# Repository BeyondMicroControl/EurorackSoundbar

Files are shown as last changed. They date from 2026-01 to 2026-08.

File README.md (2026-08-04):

# Eurorack Soundbar
Goal: A table with fitting speaker & synth electronics for a MIDI keyboard.

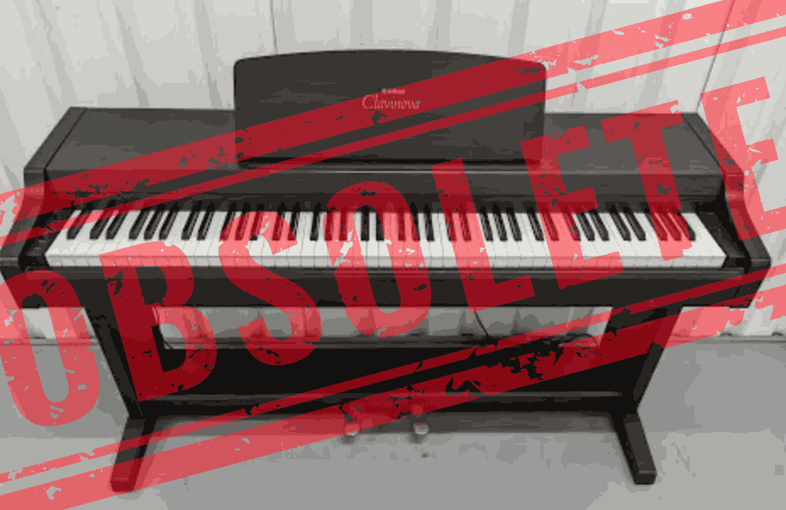
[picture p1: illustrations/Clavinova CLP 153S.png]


# Piano enclosures deserve better design
It all started with buying an all-in-one furnished hammer-action piano with built-in synth and speakers, but ending 25 years later with a shell containing a terribly old synth and procrastinating MIDI interface.  That said, while build quality on all parts of the piano gracefull survived decades of playing, electronics inside turned out to be fashion-sensitive. As a matter of fact, furniture built-in synths sooner or later all become **OBSOLETE**. I long thought about flinging out the guts out of my good old Clavinova from Yamaha built around a synth chip from 1991 (YMW258-F), but selling my old piano in its original state and figure out a more future-proof enclosure sounded like a better idea, as I really wanted an enclosure allowing more flexibility.  So, here's the plan: 
* Buy a multi-sensor MIDI keyboard - I fell for a KAWAI VPC1, but any model will do.
* Design a slim, good-looking table on wheels carrying about 30Kg=66lbs of keyboard and another 20Kg=44lbs of soundbar.
* Design a soundbar including a standardised built-in rack space for replacable electronics : **A Eurorack Soundbar as it were!**

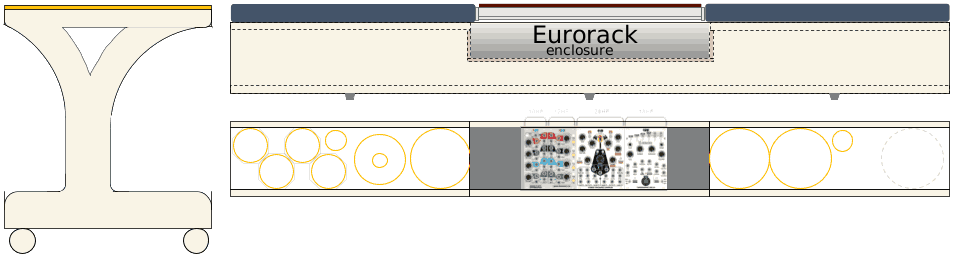
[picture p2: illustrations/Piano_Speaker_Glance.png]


# Eurorack Soundbar Requirements
## Furniture
1.1) Elegant & aesthetically matching the MIDI keyboard<br>
1.2) Providing table surface fitting Piano Keyboard + Soundbar.<br>
1.3) Sturdy enough to bear stress and strain caused by ~50Kg=110lbs of weight<br>
1.4) Providing maximum leg space horizontally and vertically.<br>
1.5) Height-adjustable to some extent.<br>
1.6) Piano-black glossy paint finish.<br>

## Speaker enclosure - passive part
2.1) Perfectly fitting keyboard width, and height aligned with the top of the speaker grills.<br>
2.2) Best compromise between good bass production and small enclosure volume.<br>
2.3) Rich sound spectrum and spatial perception ideal for instrument sound reproduction.<br>
2.4) Optional built-in passive filter and accessble attenuators whenever necessary.<br>
2.5) Die-cast, anti-reflection and airleak-proof speaker enclosure.<br>
2.6) Vibration isolation between table & enclosure.<br>
2.7) Does not vibrate or glide off the table.<br>
2.8) Re-openable, allowing replacement of speakers provided with inside fixture.<br>
2.9) All speaker leads and filter leads come straight out of the pressure cabinet. (No electrical circuits inside)<br>
2.10) One common connector (male part) providing electrically separate access to all enclosed speakers and filters.<br>
2.11) Nicely fitting speaker cover frame wrapped in speaker cover fabric, with magnetic attachment<br>
2.12) Speakers pointing upwards, providing a fairly unobstructed sound path<br>

## Electronics enclosure - active part
3.1) One common connector (female part, heading towards the amplifier) with configurable dispatching jumpers.<br>
3.2) Standard Eurorack frame housing 3U 84HP (decisive for speaker enclosure depth).<br>
3.3) Eurorack power source (Low noise 15-35V source for Amps, 5V & 3V3 regulated source for MCU's and controllers), optionally with a 1-button on/off and power-on sequence.<br>
3.4) A good compromise on the divide between Eurorack enclosure height (located between bottom plate and face plate) and speaker enclosure duct height (located under the Eurorack bottom plate).<br>
3.6) Mains inlet connector with fast fuse and manual switch.<br>
3.5) At least 3 essential Eurorack modules<br>
   - Amp (2 x 30-80W)
   - Piano connector face plate (USB-midi, MIDI-in/out)
   - Synth module (MIDI-in to audio)

3.6) Optional Eurorack modules - just brainstorming<br>
   - Battery module providing mobile power
   - Additional experimental synths (without patch cable clutter)
   - MIDI merger/splitter module
   - MIDI controller module (encoders, buttons, sliders, tone wheels, LEDs, touchscreens...)
   - MIDI sequencer / tempo

# Getting sketchy with it
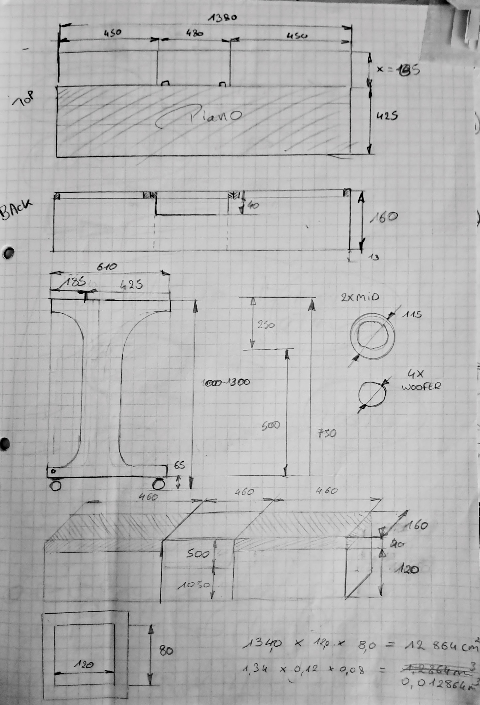
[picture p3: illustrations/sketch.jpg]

This is the initial sketch, for what it's worth, outlining all elements including the Piano; we'll come back later on the exact measures and additional features; obviously depending on the MIDI keyboard outer dimensions one has purchased.  

This is our first step, planning how this soundbar will fit best fit behind your MIDI keyboard, the outer dimensions of the table, how your knees will ideally fit under that table, and many other practical considerations.

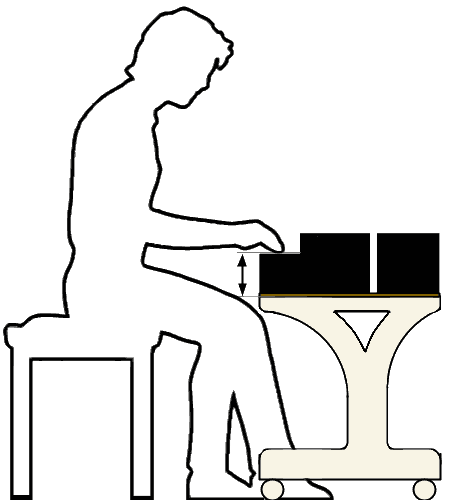
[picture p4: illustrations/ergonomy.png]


# Hardware

<a href="https://beyondmicrocontrol.github.io/AsciiCAD/index.html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">Input module</a>

# Tools

<a href=https://beyondmicrocontrol.github.io/EurorackSoundbar/tools/TOOLS_CATALOG.html>TOOLS</a>

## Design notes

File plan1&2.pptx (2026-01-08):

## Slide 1

Scrap full-range
80W 6ohm

255mm

460mm

129.5mm

255mm

PASSIVE
RADIATOR

460mm

Scrap surround system
Bass drivers 8ohm

Ebay 25W dome
Tweeter 8ohm

BASS

4

BASS

2

65mm

BASS

1

BASS

3

172mm

56mm

Volvo C70 scrap midrange dome 8ohm

56mm

172mm

7

TR

40mm

110mm

TREBLE

BASS

5

116mm

Rail from sliding door

MID

6

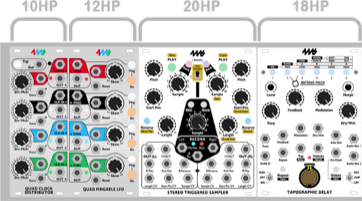
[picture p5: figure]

460mm / 5.08 = 90 HP

116mm

MID

Epoxy rain gutter plate

8

9

10

TR

40mm

OPTIONAL
BASS

146mm

7

/57

6mm

22.2mm

26mm

7.4mm

72 mm

98mm

114mm

/18

146mm

122mm

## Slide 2

1380mm

460mm

702mm

Std. Eurorack frame

speaker
textile

175mm

460mm

460mm

26mm

6mm

98mm

connector hole

137mm

140mm

160mm

/57

25mm

12mm

575mm

Rail from sliding door

375mm

12mm

50mm

Epoxy rain gutter front plate

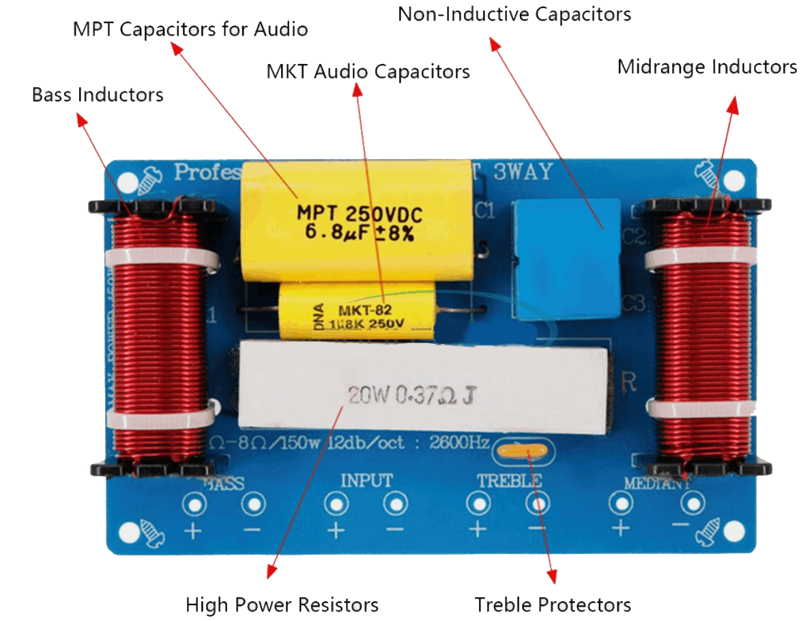
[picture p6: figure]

283mm

375mm

165mm

283mm

Passive filter
Circuit design

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
filter

8Ω

6Ω

2.2Ω

8Ω

8Ω

10

filter

2.2Ω

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
630mm

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
Connector HAT

167mm

125mm

283mm

Crossover filter

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
jumpers

102mm

F

J

J

J

J

J

J

AMP-

F

/78.7

61mm

H

M

L

L

M

H

AMP+

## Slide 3

DRAFT!!!

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
AMP-

AMP-

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
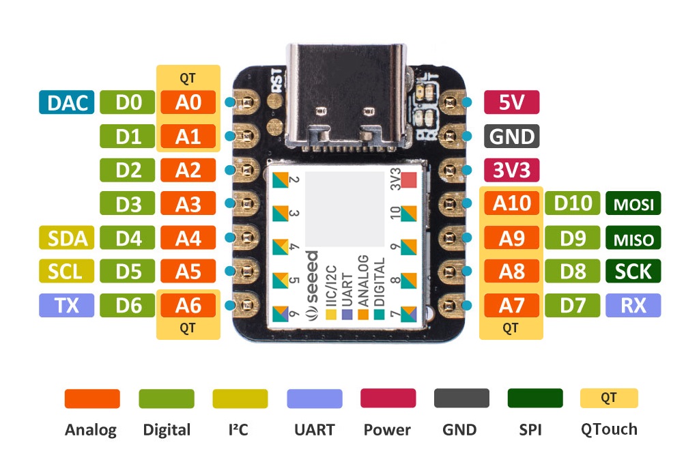
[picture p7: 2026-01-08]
illustrations/Seeeduino-XIAO-pinout-1.jpg

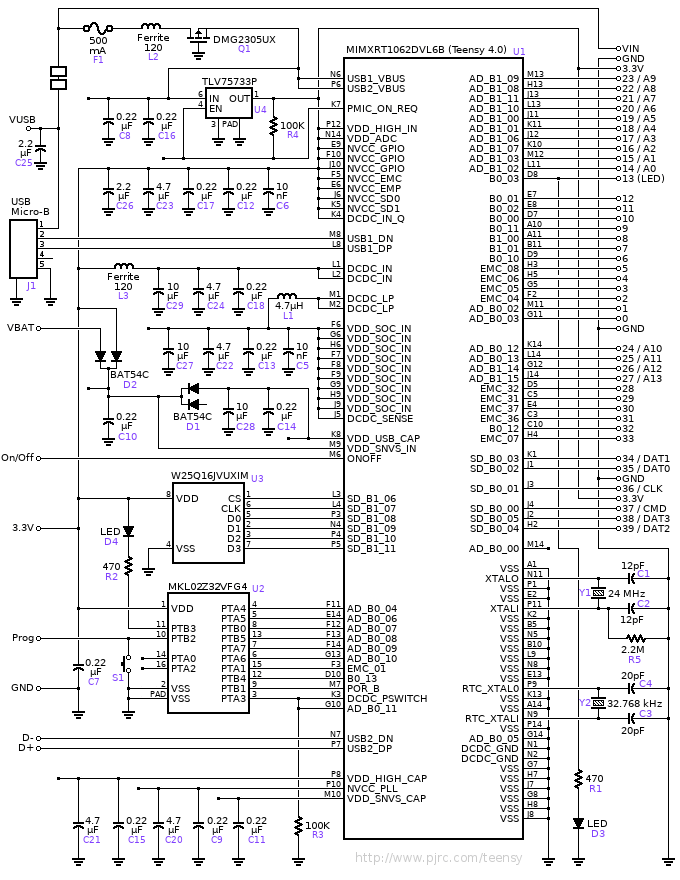
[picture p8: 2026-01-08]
arduino/Teensy40/Teensy-4.0-schematic.png

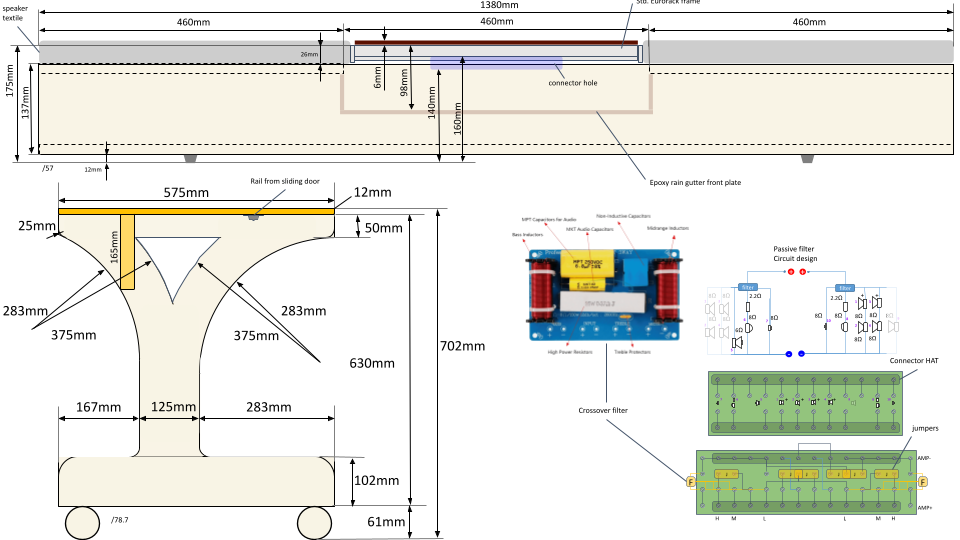
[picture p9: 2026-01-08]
plan2.png

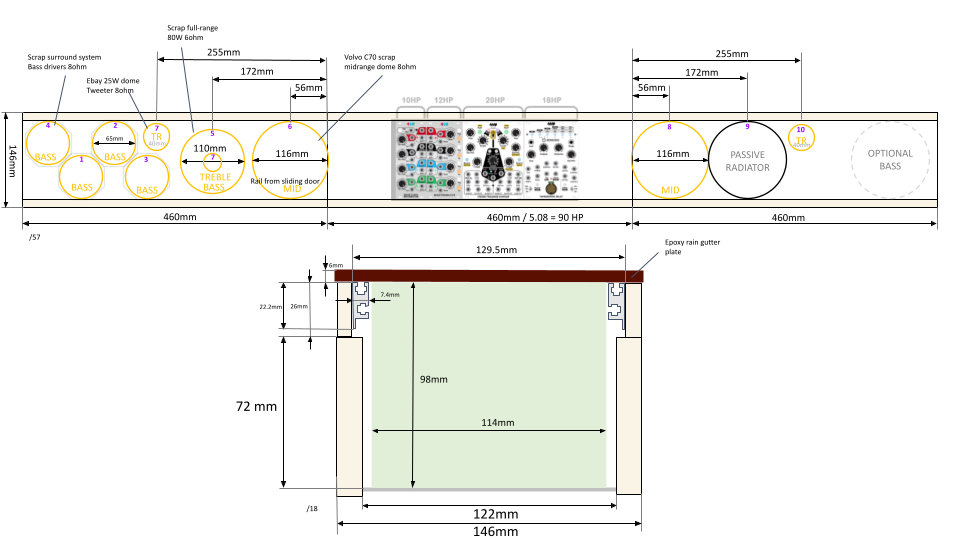
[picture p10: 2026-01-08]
plan1.png

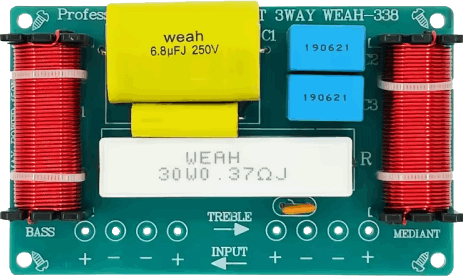
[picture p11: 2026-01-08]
illustrations/crossover-4.png

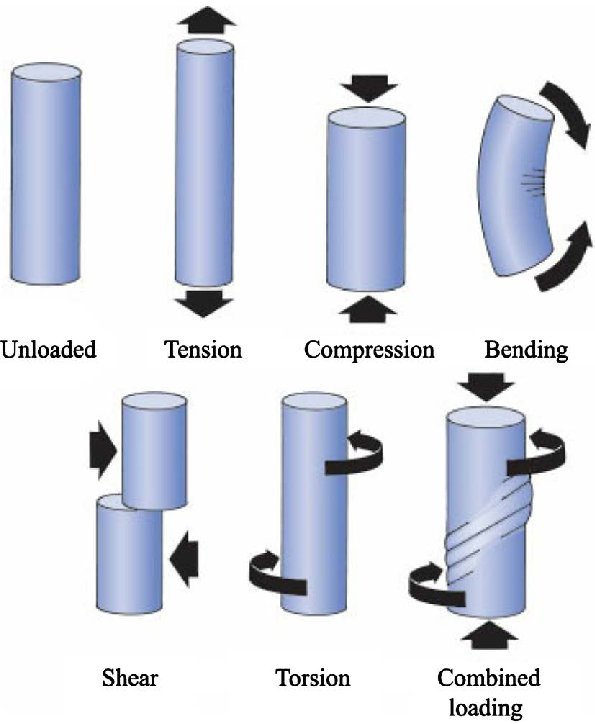
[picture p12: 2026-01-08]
illustrations/loading-cases.jpg

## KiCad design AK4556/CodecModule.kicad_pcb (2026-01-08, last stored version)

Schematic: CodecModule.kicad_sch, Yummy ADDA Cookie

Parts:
C1, C3, C4, C5: 10u; CP_Elec_4x5.4
C2, C6, C9: 100n; C_0603_1608Metric_Pad1.05x0.95mm_HandSolder
C7, C8: 22u; CP_Elec_4x5.4
C10: 2u2; CP_Elec_4x5.4
J1, J2: Conn_01x09_Female; HalfHole_2x9
R3: 5R1; R_0603_1608Metric_Pad1.05x0.95mm_HandSolder
R4, R5, R6, R7, R8: 51R; R_0603_1608Metric_Pad1.05x0.95mm_HandSolder
R9, R10, R11: 10k; R_0603_1608Metric_Pad1.05x0.95mm_HandSolder
R12, R13: 220R; R_0603_1608Metric_Pad1.05x0.95mm_HandSolder
U1: AK4556; TSSOP-20_4.4x6.5mm_P0.65mm

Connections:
+3.3VA: C5.1, C6.1, J1.4, R3.2, U1.4, U1.6
/AUDIO_INL: C4.1, J1.1
/AUDIO_INR: C3.1, J1.2
/AUDIO_OUTL: J2.9, R13.1
/AUDIO_OUTR: J2.8, R12.1
/CKS0: J1.5, U1.9
/CKS1: J1.6, U1.10
/CKS2: J1.7, U1.11
/CKS3: J1.8, U1.12
/I2S_BCLK: J2.6, R5.1
/I2S_DIN: J2.2, R8.1
/I2S_DOUT: J2.1, R4.2
/I2S_LRCLK: J2.4, R7.1
/I2S_MCLK: J2.5, R6.1
/PDN: J1.9, R11.2, U1.17
/VD: C1.1, C2.1, R3.1, U1.5
GNDA: C1.2, C2.2, C5.2, C6.2, C9.2, C10.2, J1.3, J2.3, J2.7, R9.1, R10.1, R11.1, U1.3, U1.7
unnamed: C3.2, U1.1
unnamed: C4.2, U1.2
unnamed: C7.1, U1.20
unnamed: C7.2, R9.2, R12.2
unnamed: C8.1, U1.19
unnamed: C8.2, R10.2, R13.2
unnamed: C9.1, C10.1, U1.18
unnamed: R4.1, U1.8
unnamed: R5.2, U1.16
unnamed: R6.2, U1.15
unnamed: R7.2, U1.14
unnamed: R8.2, U1.13

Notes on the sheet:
place near VD/VSS pin
De-emphasis filter off

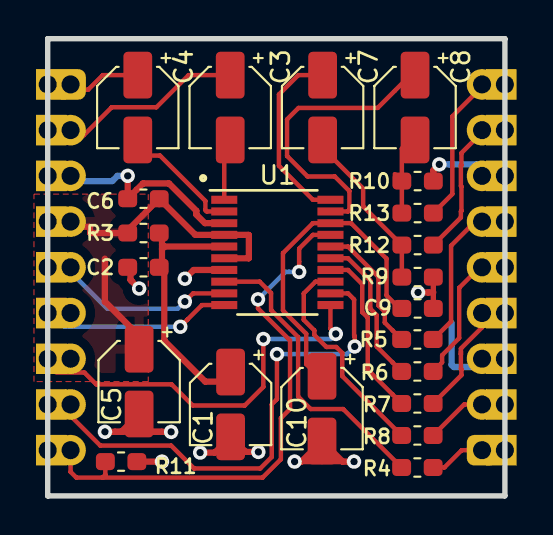
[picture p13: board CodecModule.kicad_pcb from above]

Board: 2 copper layers, 25.4 x 25.4 mm, 24 parts (0 on the bottom side), 29 nets.

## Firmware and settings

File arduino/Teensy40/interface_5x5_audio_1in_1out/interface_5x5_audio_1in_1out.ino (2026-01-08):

/* Create a "class compliant " USB to 3 MIDI IN and 3 MIDI OUT interface.

   MIDI receive (6N138 optocoupler) input circuit and series resistor
   outputs need to be connected to Serial1, Serial2 and Serial3.

   You must select MIDIx4 from the "Tools > USB Type" menu

   This example code is in the public domain.
*/

#include <MIDI.h>

// Create the Serial MIDI ports
MIDI_CREATE_INSTANCE(HardwareSerial, Serial1, MIDI1);
MIDI_CREATE_INSTANCE(HardwareSerial, Serial2, MIDI2);
MIDI_CREATE_INSTANCE(HardwareSerial, Serial3, MIDI3);
MIDI_CREATE_INSTANCE(HardwareSerial, Serial4, MIDI4);
MIDI_CREATE_INSTANCE(HardwareSerial, Serial5, MIDI5);
MIDI_CREATE_INSTANCE(HardwareSerial, Serial6, MIDI6);

// A variable to know how long the LED has been turned on
elapsedMillis ledOnMillis;
const float noteFreqs[128] = {8.176, 8.662, 9.177, 9.723, 10.301, 10.913, 11.562, 12.25, 12.978, 13.75, 14.568, 15.434, 16.352, 17.324, 18.354, 19.445, 20.602, 21.827, 23.125, 24.5, 25.957, 27.5, 29.135, 30.868, 32.703, 34.648, 36.708, 38.891, 41.203, 43.654, 46.249, 48.999, 51.913, 55, 58.27, 61.735, 65.406, 69.296, 73.416, 77.782, 82.407, 87.307, 92.499, 97.999, 103.826, 110, 116.541, 123.471, 130.813, 138.591, 146.832, 155.563, 164.814, 174.614, 184.997, 195.998, 207.652, 220, 233.082, 246.942, 261.626, 277.183, 293.665, 311.127, 329.628, 349.228, 369.994, 391.995, 415.305, 440, 466.164, 493.883, 523.251, 554.365, 587.33, 622.254, 659.255, 698.456, 739.989, 783.991, 830.609, 880, 932.328, 987.767, 1046.502, 1108.731, 1174.659, 1244.508, 1318.51, 1396.913, 1479.978, 1567.982, 1661.219, 1760, 1864.655, 1975.533, 2093.005, 2217.461, 2349.318, 2489.016, 2637.02, 2793.826, 2959.955, 3135.963, 3322.438, 3520, 3729.31, 3951.066, 4186.009, 4434.922, 4698.636, 4978.032, 5274.041, 5587.652, 5919.911, 6271.927, 6644.875, 7040, 7458.62, 7902.133, 8372.018, 8869.844, 9397.273, 9956.063, 10548.08, 11175.3, 11839.82, 12543.85};
const float DIV127 = (1.0 / 127.0);

#include <Audio.h>

// GUItool: begin automatically generated code
AudioSynthWaveformSine   sine1;          //xy=180,469
//AudioSynthWaveformSineHires   sine1;
AudioOutputMQS        mqs1;           //xy=380,468
AudioConnection          patchCord1(sine1, mqs1);
// GUItool: end automatically generated code

void setup() {
  Serial.begin(31250);
 
  pinMode(13, OUTPUT); // LED pin
  MIDI1.begin(MIDI_CHANNEL_OMNI);
  MIDI2.begin(MIDI_CHANNEL_OMNI);
  MIDI3.begin(MIDI_CHANNEL_OMNI);
  MIDI4.begin(MIDI_CHANNEL_OMNI);
  MIDI5.begin(MIDI_CHANNEL_OMNI);
  MIDI6.begin(MIDI_CHANNEL_OMNI);
  MIDI1.turnThruOff();
  MIDI2.turnThruOff();
  MIDI3.turnThruOff();
  MIDI4.turnThruOff();
  MIDI5.turnThruOff();
  MIDI6.turnThruOff();


  AudioMemory(12);
  sine1.amplitude(0.0);
  sine1.frequency(1000);
 
    digitalWriteFast(13, HIGH); // LED on
    delay(1500);
    digitalWriteFast(13, LOW);
}


void loop() {
  bool activity = false;

  if (MIDI1.read()) {
    // get a MIDI IN1 (Serial) message
    byte type = MIDI1.getType();
    byte channel = MIDI1.getChannel();
    byte data1 = MIDI1.getData1();
    byte data2 = MIDI1.getData2();

    // forward the message to USB MIDI virtual cable #0
    if (type != midi::SystemExclusive) {
      // Normal messages, simply give the data to the usbMIDI.send()
      usbMIDI.send(type, data1, data2, channel, 0);
      MIDI1.send(static_cast<midi::MidiType>(type), data1, data2, channel);
      MIDI6.send(static_cast<midi::MidiType>(type), data1, data2, channel);
 
   /* 
      MIDI2.send(type, data1, data2, channel);
      MIDI3.send(type, data1, data2, channel);      
      MIDI4.send(type, data1, data2, channel);  
      MIDI5.send(type, data1, data2, channel);  
   */

      char c[256];
      sprintf(c,"%d %d %d",data1,data2,channel);
      Serial.println(c);
   
    } else {
      // SysEx messages are special.  The message length is given in data1 & data2
      unsigned int SysExLength = data1 + data2 * 256;
      usbMIDI.sendSysEx(SysExLength, MIDI1.getSysExArray(), true, 0);
 /*   MIDI1.sendSysEx(SysExLength, MIDI1.getSysExArray(), true);
      MIDI2.sendSysEx(SysExLength, MIDI1.getSysExArray(), true);
      MIDI3.sendSysEx(SysExLength, MIDI1.getSysExArray(), true);
      MIDI4.sendSysEx(SysExLength, MIDI1.getSysExArray(), true);
      MIDI5.sendSysEx(SysExLength, MIDI1.getSysExArray(), true);
   */
   
    }
    activity = true;
  }

  if (MIDI2.read()) {
    // get a MIDI IN2 (Serial) message
    byte type = MIDI2.getType();
    byte channel = MIDI2.getChannel();
    byte data1 = MIDI2.getData1();
    byte data2 = MIDI2.getData2();

    // forward the message to USB MIDI virtual cable #1
    if (type != midi::SystemExclusive) {
      // Normal messages, simply give the data to the usbMIDI.send()
      usbMIDI.send(type, data1, data2, channel, 1);
/*      MIDI1.send(type, data1, data2, channel);
      MIDI2.send(type, data1, data2, channel);
      MIDI3.send(type, data1, data2, channel);  
      MIDI4.send(type, data1, data2, channel);  
      MIDI5.send(type, data1, data2, channel);  
  */    
    } else {
      // SysEx messages are special.  The message length is given in data1 & data2
      unsigned int SysExLength = data1 + data2 * 256;
      usbMIDI.sendSysEx(SysExLength, MIDI2.getSysExArray(), true, 1);
  /*    MIDI1.sendSysEx(SysExLength, MIDI2.getSysExArray(), true);
      MIDI2.sendSysEx(SysExLength, MIDI2.getSysExArray(), true);
      MIDI3.sendSysEx(SysExLength, MIDI2.getSysExArray(), true);
      MIDI4.sendSysEx(SysExLength, MIDI2.getSysExArray(), true);
      MIDI5.sendSysEx(SysExLength, MIDI2.getSysExArray(), true);      
  */  
    }
    activity = true;
  }

  if (MIDI3.read()) {
    // get a MIDI IN1 (Serial) message
    byte type = MIDI3.getType();
    byte channel = MIDI3.getChannel();
    byte data1 = MIDI3.getData1();
    byte data2 = MIDI3.getData2();

    // forward the message to USB MIDI virtual cable #0
    if (type != midi::SystemExclusive) {
      // Normal messages, simply give the data to the usbMIDI.send()
      usbMIDI.send(type, data1, data2, channel, 2);
  /*    MIDI1.send(type, data1, data2, channel);
      MIDI2.send(type, data1, data2, channel);
      MIDI3.send(type, data1, data2, channel);
      MIDI4.send(type, data1, data2, channel);  
      MIDI5.send(type, data1, data2, channel);          
   */  
    } else {
      // SysEx messages are special.  The message length is given in data1 & data2
      unsigned int SysExLength = data1 + data2 * 256;
      usbMIDI.sendSysEx(SysExLength, MIDI3.getSysExArray(), true, 2);
 /*     MIDI1.sendSysEx(SysExLength, MIDI3.getSysExArray(), true);
      MIDI2.sendSysEx(SysExLength, MIDI3.getSysExArray(), true);
      MIDI3.sendSysEx(SysExLength, MIDI3.getSysExArray(), true);
      MIDI4.sendSysEx(SysExLength, MIDI3.getSysExArray(), true);
      MIDI5.sendSysEx(SysExLength, MIDI3.getSysExArray(), true);      
 */  
    }
    activity = true;
  }

  if (MIDI4.read()) {
    // get a MIDI IN1 (Serial) message
    byte type = MIDI4.getType();
    byte channel = MIDI4.getChannel();
    byte data1 = MIDI4.getData1();
    byte data2 = MIDI4.getData2();

    // forward the message to USB MIDI virtual cable #0
    if (type != midi::SystemExclusive) {
      // Normal messages, simply give the data to the usbMIDI.send()
      usbMIDI.send(type, data1, data2, channel, 3);
 /*     MIDI1.send(type, data1, data2, channel);
      MIDI2.send(type, data1, data2, channel);
      MIDI3.send(type, data1, data2, channel);
      MIDI4.send(type, data1, data2, channel);  
      MIDI5.send(type, data1, data2, channel);          
  */    
    } else {
      // SysEx messages are special.  The message length is given in data1 & data2
      unsigned int SysExLength = data1 + data2 * 256;
      usbMIDI.sendSysEx(SysExLength, MIDI4.getSysExArray(), true, 3);
  /*    MIDI1.sendSysEx(SysExLength, MIDI4.getSysExArray(), true);
      MIDI2.sendSysEx(SysExLength, MIDI4.getSysExArray(), true);
      MIDI3.sendSysEx(SysExLength, MIDI4.getSysExArray(), true);
      MIDI4.sendSysEx(SysExLength, MIDI4.getSysExArray(), true);
      MIDI5.sendSysEx(SysExLength, MIDI4.getSysExArray(), true);      
   */
    }
    activity = true;
  }

  if (MIDI5.read()) {
    // get a MIDI IN1 (Serial) message
    byte type = MIDI5.getType();
    byte channel = MIDI5.getChannel();
    byte data1 = MIDI5.getData1();
    byte data2 = MIDI5.getData2();

    // forward the message to USB MIDI virtual cable #0
    if (type != midi::SystemExclusive) {
      // Normal messages, simply give the data to the usbMIDI.send()
      usbMIDI.send(type, data1, data2, channel, 4);
/*      MIDI1.send(type, data1, data2, channel);
      MIDI2.send(type, data1, data2, channel);
      MIDI3.send(type, data1, data2, channel);
      MIDI4.send(type, data1, data2, channel);  
      MIDI5.send(type, data1, data2, channel);          
  */    
    } else {
      // SysEx messages are special.  The message length is given in data1 & data2
      unsigned int SysExLength = data1 + data2 * 256;
      usbMIDI.sendSysEx(SysExLength, MIDI5.getSysExArray(), true, 4);
 /*     MIDI1.sendSysEx(SysExLength, MIDI5.getSysExArray(), true);
      MIDI2.sendSysEx(SysExLength, MIDI5.getSysExArray(), true);
      MIDI3.sendSysEx(SysExLength, MIDI5.getSysExArray(), true);
      MIDI4.sendSysEx(SysExLength, MIDI5.getSysExArray(), true);
      MIDI5.sendSysEx(SysExLength, MIDI5.getSysExArray(), true);      
 */  
   
    }
    activity = true;
  }



  if (usbMIDI.read()) {
    // get the USB MIDI message, defined by these 5 numbers (except SysEX)
    byte type = usbMIDI.getType();
    byte channel = usbMIDI.getChannel();
    byte data1 = usbMIDI.getData1();
    byte data2 = usbMIDI.getData2();
    byte cable = usbMIDI.getCable();

    // forward this message to 1 of the 3 Serial MIDI OUT ports
    if (type != usbMIDI.SystemExclusive) {
      // Normal messages, first we must convert usbMIDI's type (an ordinary
      // byte) to the MIDI library's special MidiType.
      midi::MidiType mtype = (midi::MidiType)type;

      // Then simply give the data to the MIDI library send()
      switch (cable) {
        case 0:
          MIDI1.send(mtype, data1, data2, channel);
          break;
        case 1:
          MIDI2.send(mtype, data1, data2, channel);
          break;
        case 2:
          MIDI3.send(mtype, data1, data2, channel);
          break;
        case 3:
          MIDI4.send(mtype, data1, data2, channel);
          break;
        case 4:
          MIDI5.send(mtype, data1, data2, channel);
          break;
        case 5:
          switch (type) {
           case midi::NoteOn:
            sine1.frequency(noteFreqs[data1]);
            sine1.amplitude(data2 * DIV127);
           
           break;
           
           case midi::NoteOff:
            sine1.amplitude(0.0);
           break;
          }
           
          break;
      }

    } else {
      // SysEx messages are special.  The message length is given in data1 & data2
      unsigned int SysExLength = data1 + data2 * 256;
      switch (cable) {
        case 0:
          MIDI1.sendSysEx(SysExLength, usbMIDI.getSysExArray(), true);
          break;
        case 1:
          MIDI2.sendSysEx(SysExLength, usbMIDI.getSysExArray(), true);
          break;
        case 2:
          MIDI3.sendSysEx(SysExLength, usbMIDI.getSysExArray(), true);
          break;
        case 3:
          MIDI4.sendSysEx(SysExLength, usbMIDI.getSysExArray(), true);
          break;
        case 4:
          MIDI5.sendSysEx(SysExLength, usbMIDI.getSysExArray(), true);
          break;  
      }
    }
    activity = true;
  }

  // blink the LED when any activity has happened
  if (activity) {
    digitalWriteFast(13, HIGH); // LED on
    ledOnMillis = 0;
  }
  if (ledOnMillis > 15) {
    digitalWriteFast(13, LOW);  // LED off
  }

}

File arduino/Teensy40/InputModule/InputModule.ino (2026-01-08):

/*


  ╔══════════════════════════════════╗
  ║           ╰──USB──╯              ║
  ║                                  ║
  ║         [Teensy 4.0]             ║
  ║      ARM Cortex-M7 600MHz        ║
  ║                                  ║
 ─╢GND                            VIN╟─
╳─╢RX1  CRX2   -0                 GND╟──⎡⎤──────┬──────┐
╳─╢TX1  CTX2   -1                 3V3╟──┤│──────│──────┼───┐
 ─╢     OUT2   -2  23- MCLK1 CRX1  A9╟──┤│────┐ │      │   │
 ─╢     LRCLK2 -3  22-       CTX1  A8╟──⎣⎦──┐ │ │      │   │
 ─╢     BCLK2  -4  21- BCLK1  RXS  A7╟─╳    │ │ │      │   │
 ─╢     IN2    -5  20-        TXS  A6╟─╳    │ │ │      │   │
 ─╢     OUT1D  -6  19-  SCL0       A5╟──⎡⎤──│─│─│──────┼───┼───┐
╳─╢RX2  OUT1A  -7  18-  SDA0       A4╟──⎣⎦──│─│─│──────┼───┼───┼───┐
╳─╢TX2  IN1    -8  17-  SDA1  TX4  A3╟─╳    │ │ │      │   │   │   │
 ─╢     OUT1C  -9  16-  SCL1  RX4  A2╟─╳    │ │ │  ╔═══╧═══╧═══╧═══╧═══╗
╳─╢MQSR CS     -10 15-        RX3  A1╟─╳    │ │ │  ║  GND VCC SCL SDA  ║
 ─╢MOSI CTX1   -11 14-        TX3  A0╟─╳    │ │ │  ║                   ║
╳─╢MISO MQSL   -12 13- CRX1   SCK LED╟─     │ │ │  ║┌─────────────────┐║
  ║                                  ║      │ │ │  ║│                 │║
  ╚══════════════════════════════════╝      │ │ │  ║│    [SSD1306]    │║
                  ┌─────────────────────────┘ │ │  ║│  64 x 32 OLED   │║
                  │ ╷     ╷                   │ │  ║│                 │║
                  └•⎺•─┬─•⎺•──────────────────┘ │  ║└─────────────────┘║
                       └────────────────────────┘  ╚═══════════════════╝


*/


#define OLEDSCOPE_DEBUG
//#define OLEDSCOPE_WIPER
#define SCOPE_PIN          A9
#define TINY4KOLED_WIDTH   64
#define TINY4KOLED_HEIGHT  32
//#define TINY4KOLED_MOD   r

#include "OLEDscope_v1.h"
OLEDscope scope;
uint8_t  x=0;
uint8_t  cnt=0;
uint32_t i2c_speed=0;


#ifdef OLEDSCOPE_DEBUG
          #include "zxpix_font.h"
          #define FONTZXPIX (&TinyOLEDFontzxpix)
          const DCfont *currentFont = FONTZXPIX;
#endif

void setup()
{

  
#ifdef OLEDSCOPE_DEBUG
          oled.setFont(currentFont);
#endif

    pinMode(SCOPE_PIN, INPUT);
    #ifdef LED_PIN
    pinMode(LED_PIN,OUTPUT);
    #endif
    //oled.begin(TINY4KOLED_WIDTH, TINY4KOLED_HEIGHT, sizeof(tiny4koled_init_64x32r), tiny4koled_init_64x32r);
    oled.begin(TINY4KOLED_WIDTH, TINY4KOLED_HEIGHT, sizeof(TINY4KOLED_INI), TINY4KOLED_INI);

    
    //Wire.setClock(100000);   // 100000 = 100 kHz, 400000 = 400 kHz (common fast-mode), 1000000 = 1MHz (ultra-fast)
    //Wire.setClock(400000);
    Wire.setClock(1000000);

    scope.begin();
    scope.debug();
}

void loop()
{
    if(cnt>63)
    {
      i2c_speed+=100;
      //Wire.setClock(i2c_speed);
      cnt=0;
    }
    cnt++;
    
    uint8_t y = analogRead(SCOPE_PIN) >> 2;
    //uint8_t y = digitalRead(SCOPE_PIN)?255:0;
    //uint8_t y = (1+sin(x/(2.5*3.14))) * 127;
    //uint8_t y = 20 * (64-x);
    //uint8_t y = x%10<5?(22*4):i;      // range 0-255

    scope.update(y);
    #ifdef LED_PIN
    if(y > 128)
         digitalWrite(LED_PIN,HIGH);
    else digitalWrite(LED_PIN,LOW);
    #endif

    x = x<TINY4KOLED_WIDTH-1?x+1:0;
}
